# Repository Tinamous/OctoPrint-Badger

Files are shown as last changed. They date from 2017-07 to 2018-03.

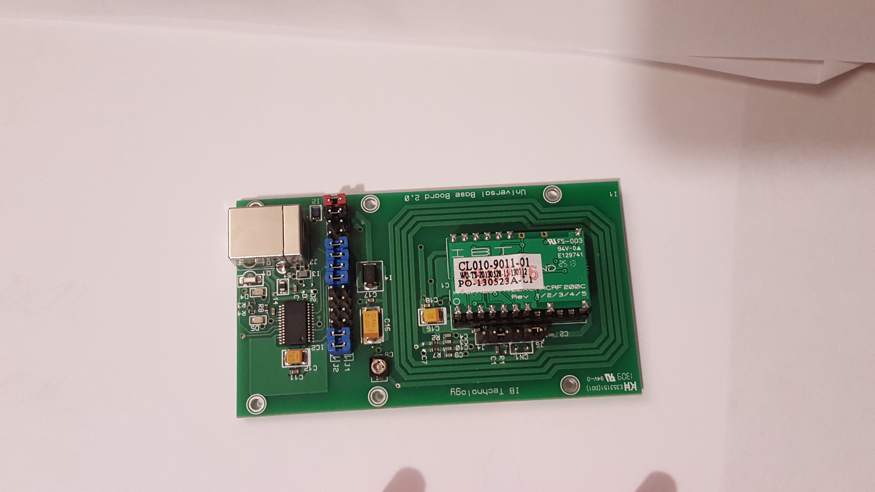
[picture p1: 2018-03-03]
Images/2017-08-05 03.23.46.jpg

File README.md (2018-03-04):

# OctoPrint-Badger

Prints 2D Badges/Labels.

Uses OctoPrint system to allow for "Do No Hack" labels to be printed on a Dymo Label Writer (for MakeSpace) using RFID tags.

Not really used for 3D printing unless you wish to modify and automate to print labels for when a print is finished or something.

## Setup

Hardware setup:

* Raspberry Pi 3
* Dymo LabelWriter 450
* IB Technology Micro RWD RFID reader (for Makespace door kep)
* 2x 28mm Arcade buttons with LEDs (Optional)
* Pi Power Hat (https://github.com/Tinamous/PiPowerHat) (optional) or 5V DC supply for Raspberry Pi
* Labels, lots of...

### Buttons:

Left Button:

* Switch Pin 1: GND
* Switch Pin 2: GPIO 26
* LED Pin 1: GND
* LED Pin 2: via 82R resistor to GPIO 16

Right Button: 

* Switch Pin 1: GND
* Switch Pin 2: GPIO 21
* LED Pin 1: GND
* LED Pin 2: via 82R resistor to GPIO 20

LED Indicator:

* GPIO 11 with 1k resistor going to GND (this is build on-board the Pi Power Hat)

### Software Installation

* Download and install OctoPi (https://octoprint.org/download/)
* Follow the Getting Started Guide for OctoPi.
* Install Cups
* Download and install the Dymo 450

#### Install CUPS:

sudo apt-get install libcups2-dev libcupsimage2-dev g++ cups cups-client

#### Install Dymo 450 Printer

The driver can be downloaded from:

http://www.dymo.com/en-US/dymo-label-sdk-and-cups-drivers-for-linux-dymo-label-sdk-cups-linux-p--1#

For convenience it's also in this repository:

* wget https://github.com/Tinamous/OctoPrint-Badger/raw/master/Notes/dymo-cups-drivers-1.4.0.tar.gz

* tar xvf dymo-cups-drivers-1.4.0.tar.gz
* cd dymo-cups-drivers-1.4.0.5/
* sudo ./configure
* sudo make
* sudo make install

Then add the Pi user to the printing group and enable remote admin

* sudo usermod -a -G lpadmin pi
* cupsctl --remote-admin

You should now be able to open a browser to the CUPS server:

* https://octopi.local:631/
* Add the printer (Administration/Add Printer/Select the 450).
* Select the label size (99012), quality (300x600) and select Barcode and Graphics as the default

#### Install OctoPrint-Badger plugin

Install via the bundled [Plugin Manager](https://github.com/foosel/OctoPrint/wiki/Plugin:-Plugin-Manager)
or manually using this URL:

    https://github.com/Tinamous/OctoPrint-Badger/archive/master.zip

The registration plug-in will most likely be needed as well, grab that from https://github.com/Tinamous/OctoPrint-Registration

Once installed configure the pluging settings to use the appropriate printer and RFID reader.

#### Remove Unwanted OctoPrint bits.

* cd ~/.octoprint/
* sudo nano config.yaml

Add/Update the following:

appearance:
  components:
    disabled:
      tab:
      - temperature
      - gcodeviewer
      - terminal
      - control
      - plugin_pipower
      - timelapse
      sidebar:
      - connection
      - state
      - files
    order:
      tab:
      - plugin_whosprinting

## Configuration

This is work in progress. Requires CUPS support to be installed. Please see the Notes folder for the time being.

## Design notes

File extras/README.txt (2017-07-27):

Currently Cookiecutter generates the following helpful extras to this folder:

Badger.md
    Data file for plugins.octoprint.org. Fill in the missing TODOs once your
    plugin is ready for release and file a PR as described at
    http://plugins.octoprint.org/help/registering/ to get it published.

This folder may be safely removed if you don't need it.

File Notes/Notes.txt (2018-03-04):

apt-get update
apt-get upgrade 

From: https://community.ubnt.com/t5/UniFi-Wireless/RPI-Dashbutton-Turn-RaspberryPI-with-Dymo-LabelWriter-into-a/td-p/1667513

sudo apt-get install libcups2-dev libcupsimage2-dev g++ cups cups-client

- Linux drivers: Download from: http://www.dymo.com/en-US/dymo-label-sdk-and-cups-drivers-for-linux-dymo-label-sdk-cups-linux-p--1#

Or get it from the project repository...
wget https://github.com/Tinamous/OctoPrint-Badger/raw/master/Notes/dymo-cups-drivers-1.4.0.tar.gz

tar xvf dymo-cups-drivers-1.4.0.tar.gz
cd dymo-cups-drivers-1.4.0/
sudo ./configure
sudo make
sudo make install

# Add Pi user to printers group

sudo usermod -a -G lpadmin pi

---
Add printer using cups...

Enable cups to be accessed off the pi
cupsctl --remote-admin

Browse to cups..
https://octopi.local:631/

Connect Dymo printer.

Add Dymo, set Media size to 11356 (White Name Badge - need to change this to something smaller)
Print Quality: Barcodes and Graphics)

NB:99012 actual label (Large Address 36mm x 89mm)

connection: usb://DYMO/LabelWriter%20450?serial=01010112345600

Not appropriate, but...
git clone https://github.com/Makespace/Badger

# Python imple - before adding plugin.

# Needed for python
sudo apt-get install python-cups

# See https://pypi.python.org/pypi/pycups

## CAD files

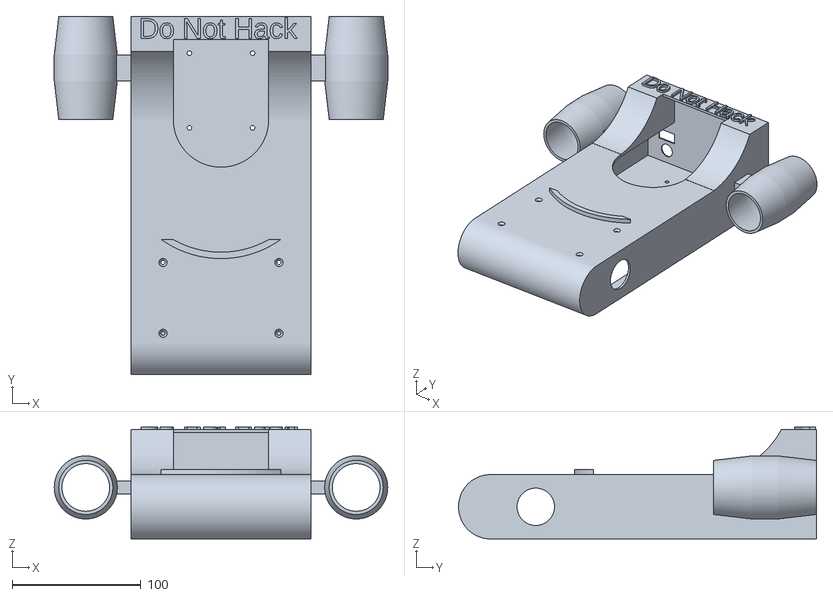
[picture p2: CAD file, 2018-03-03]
Case/OctoBadgerCase-full-WithEngines.stl
259.0 x 278.0 x 86.9

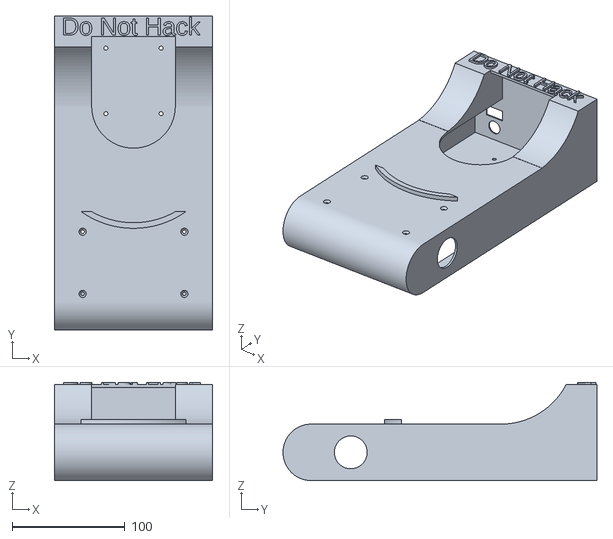
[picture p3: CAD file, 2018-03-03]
Case/OctoBadgerCase-full.stl
140.0 x 278.0 x 86.9

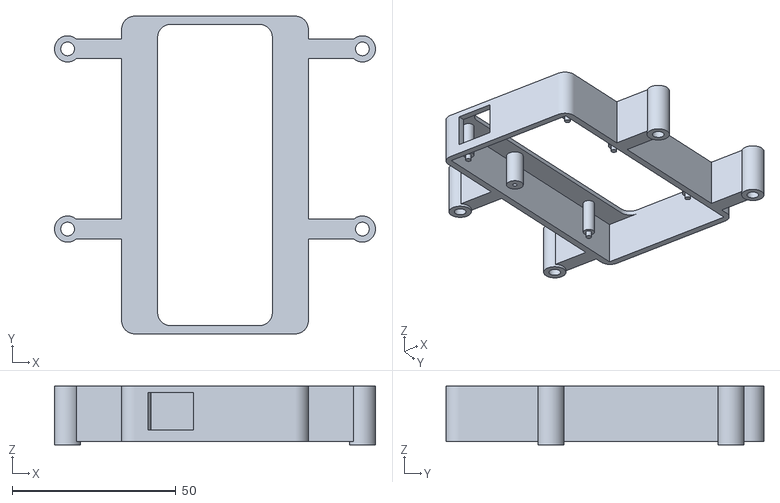
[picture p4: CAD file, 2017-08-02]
Case/RFID Sensor Mounts/CaseForRfidUniversalPcb.stl
98.0 x 97.0 x 18.0

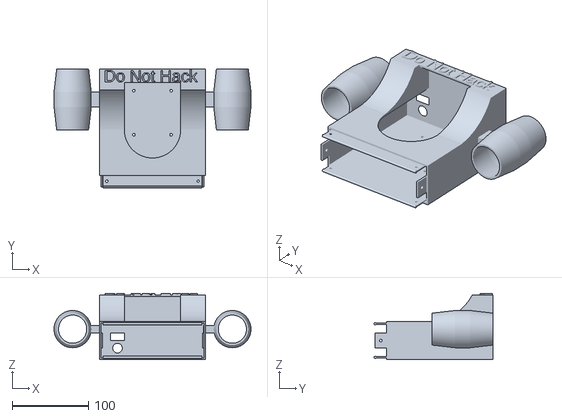
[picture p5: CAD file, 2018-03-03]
Case/OctoBadgerCase-Rear-WithEngines.stl
259.0 x 156.5 x 86.9

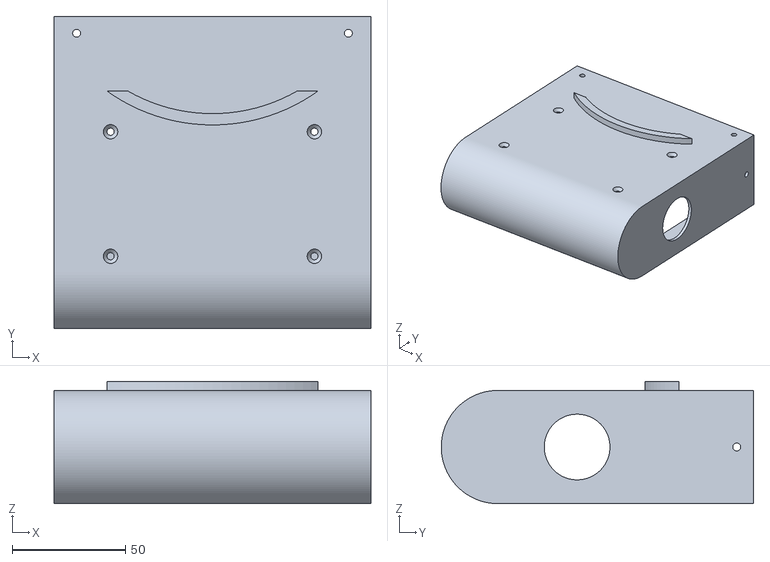
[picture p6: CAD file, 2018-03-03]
Case/OctoBadgerCase-front.stl
140.0 x 138.0 x 54.0

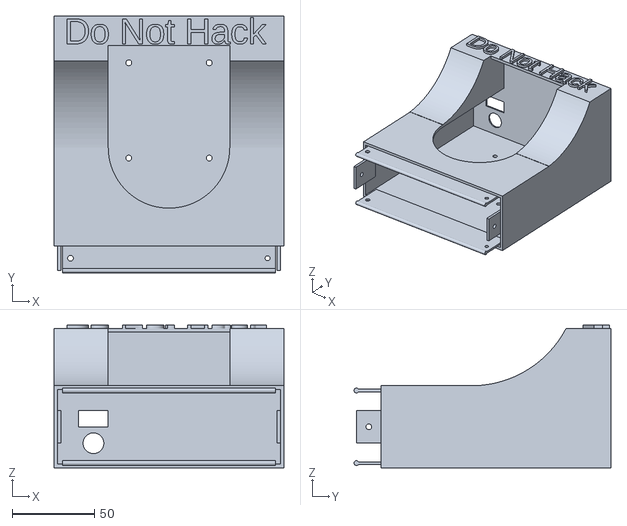
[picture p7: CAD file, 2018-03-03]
Case/OctoBadgerCase-Rear.stl
140.0 x 156.5 x 86.9

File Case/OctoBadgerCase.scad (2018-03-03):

caseWidth = 140; // Was 110 but label writer sticks out 10mm on each side 
caseHeight = 50; //45
$fn=120;

//rfidCaseLength = 125;
rfidCaseLength = 113;
wallWidth = 2;
// Allow for the join esction lip.
piCaseWallWidth = wallWidth + 0.2;

//printAllAtOnce = true;
printRfidSection = true;
printPiSection = true;
printPiEngines = true;
// If printing both at the same time then
// don't bother with the joing section and holes.
printAllAtOnce = printRfidSection && printPiSection;

includeSideButtons = true;
switchCutoutDiameter = 29;

includeUsbHole = false;

module showModels() {
    // Our case is 110mm wide
    // dymo is 125 so hase 15mm overhand (7.5mm each side)
    // back Pi case to start 70mm in (at our y=0)
    // front RFID case to be about 50mm in front of the printer
    translate([(caseWidth - 125)/2,-65,caseHeight + 00]) {
        //%labelWriter();
    }

    if (printPiSection) {
        // Place the Pi dead centeral.
        translate([(caseWidth - 56)/2, 35, 5]) {
            %raspberryPi();
        }
    }

    if (printRfidSection) {        
        translate([(caseWidth - 57)/2, -rfidCaseLength -3, caseHeight-20]) {    
          //  %rfidModule();
        }
    }
}

// Show a model of the Raspberry Pi to check sizing
module raspberryPi() {
    
    // Rasberry Pi main body
    cube([56, 80, 30]); // 65mm + USB/Ethernet port.
    
    // USB Connections
    translate([56-35,-53,5]) {
        cube([35, 53, 30]);
    }
    
    translate([5,80,30]) {
        cube([12, 20, 20]);
    }
    
    // With connectors and supports.
    cube([56, 80, 45]);
    
    // 4 Pin power connector (connect printer power when running 24V into Pi Power Hat)
    translate([3,80-25,30]) {
        cube([12, 4, 20]);
    }
    
    // Holes.
    translate([0,80-65,-10]) {
        piScrewHoles(2.8);
    }
}

module piScrewHoles(d) {
h = 40;
    translate([3.5,3.5,0]) {
        cylinder(d=d,h=h);
    }
    translate([52.5,3.5,0]) {
        cylinder(d=d,h=h);
    }
    translate([52.5,61.5,0]) {
        cylinder(d=d,h=h);
    }
    translate([3.5,61.5,0]) {
        cylinder(d=d,h=h);
    }
}

// Show a model of the RFID module to check sizing
module rfidModule() {
    cube([57, 97, 18]);
    
    // Hidhlight the rfid area
    // aerial 57mm diameter, 3mm offset from case edge + 5mm from pcb
    translate([57/2,57/2+5,10]) {
        cylinder(d=50, h=20);
    }

    
    // USB Plug
    translate([5,90,6]) {
        #cube([12, 50, 12]);
    }
    
    // Centered.
    //translate([(caseWidth - 50)/2 + 50, -140+10, caseHeight-5]) {    
        
    // Holes 90mm appart
    // rfid case is 57mm.
    translate([-(90-57)/2, 10, 0]) {    
        rfidScrewHoles(3.2);
    }
}

// Holes in rfid case 90 x 60mm appart.
module rfidScrewHoles(d) {
    
h=60;
    translate([0,0,0]) {
        cylinder(d=d,h=h);
    }
    translate([90,0,0]) {
        cylinder(d=d,h=h);
    }
    translate([0,55,0]) {
        cylinder(d=d,h=h);
    }
    translate([90,55,0]) {
        cylinder(d=d,h=h);
    }
}

module rfidScrewHolesCountersunk(d) {
    
h=wallWidth+0.2;
d2 = 6.5; // M3 countsunk head size
    translate([0,0,0]) {
        cylinder(d1=d,d2=d2, h=h);
    }
    translate([90,0,0]) {
        cylinder(d1=d,d2=d2,h=h);
    }
    translate([0,55,0]) {
        cylinder(d1=d,d2=d2,h=h);
    }
    translate([90,55,0]) {
        cylinder(d1=d,d2=d2,h=h);
    }
}
    

module labelWriter() {
    difference() {
        union() {
            cube([125, 185, 140]);
        }
        union(){ 
            translate([(125 - 55)/2, 125 ,-0.1]) {
                cube([55, 45, 20]);
            }
            translate([(125 - 40)/2, 125 ,-0.1]) {
                cube([40, 65, 20]);
            }
        }
    }
}

baseCutout = 100;
baseCutoutOffset = (caseWidth - baseCutout)/2;

// Rear half of the case containing the Raspberry
// Pi.
module piCase() {
    
    
    // Front Section of the back half
    difference() {
        union() {
            cube([caseWidth, 60, caseHeight]);
        }
        union() {
            // Hollow the part below the printer
            translate([piCaseWallWidth,-1,piCaseWallWidth]) {
                cube([caseWidth-(piCaseWallWidth*2), 62, caseHeight-(piCaseWallWidth*2)]);
            }
                        
            // Put a curve in the top to help 
            translate([caseWidth/2,60,caseHeight-5]) {
                rotate([0,0,90]) {
                    cylinder(d=74, h=10);
                }
            }
            
            // This section overlaps with the back so ensure we have 
            // the screwholes set here as well.
            translate([(caseWidth - 56)/2,60 - 10,-5]) {
                #piScrewHoles(3.6);
            }
        }
    }
    
    
    // Back section of the back half
    translate([0,60,0]) {
        difference() {
            union() {
                cube([caseWidth, 80, 35 + caseHeight]);
            }
            union() {               
                // Hollow the part below the printer
                translate([piCaseWallWidth,-0.1,piCaseWallWidth]) {
                    cube([caseWidth-(piCaseWallWidth*2), 80-0.9, caseHeight-(piCaseWallWidth*2)]);
                }
                
                // Curve the end for the printer to sit into
                translate([-0.1,-5,caseHeight + 65]) {
                    rotate([0,90,0]) {
                        cylinder(d=130, h=caseWidth+0.2);
                    }
                }
                
                // Cut out the square recess for printer cable
                translate([(caseWidth-74)/2,-1,caseHeight-(piCaseWallWidth+1)]) {
                    cube([74, 80, 38 - piCaseWallWidth]);
                }
                
                // Repeat cutout but to include part of the top section as well.
                translate([(caseWidth-74)/2,-1,caseHeight-2]) {
                    cube([74, 54 + 9, 40]);
                }
                
                // Hole for the power connector.
                powerHoleDiameter = 12.6;
                //translate([caseWidth/2,82,70]) {
                translate([15+9,82,10 + 5]) {
                    rotate([90,0,0]) {
                        cylinder(d=powerHoleDiameter, h=5);
                    }
                }
                
                // Hole for USB lead for Pi.
                if (includeUsbHole) {
                    translate([15,75,25]) {
                            #cube([18, 10, 10]);
                    }
                }
                
                // Holes for Raspberry Pi.
                translate([(caseWidth - 56)/2,-10,-5]) {
                    piScrewHoles(3.6);
                }
            }
        }
    }
    
    if (!printAllAtOnce) {
        // Add joint senction to help join to the rfid section
        difference() {
            union() {           
                // Use RFID wall width (smaller than this)
                // to align the joint section with the rfid case
                
                translate([wallWidth+0.1,-15,wallWidth+0.1]) {
                    // wallWidth is wall width
                    // so 0.1mm smaller all around
                    //cube([caseWidth - 3.6, 25, caseHeight - 3.6]);
                }
                
                translate([5,-15, wallWidth+0.1]) {
                    #cube([caseWidth-10, 25,1.6]);
                    translate([0,0,1.6/2]) {
                        rotate([0,90,0]) {
                            cylinder(d=3, h=caseWidth-10);
                        }
                    }
                }
                
                // 2mm thick so drop down 2.1mm for thickness
                // + fitting tollerance.
                translate([5,-15,caseHeight - (wallWidth+1.7)]) {
                    #cube([caseWidth-10, 25,1.6]);
                    translate([0,0,1.6/2]) {
                        rotate([0,90,0]) {
                            cylinder(d=3, h=caseWidth-10);
                        }
                    }
                }
                
                // Side parts for bolts.
                translate([wallWidth+0.1,-15,(caseHeight/2)-10]) {
                    cube([2, 25,20]);
                }
                
                translate([caseWidth - (wallWidth+0.1+2),-15,(caseHeight/2)-10]) {
                    cube([2, 25,20]);
                }
                
                // TODO: Add M4 Cylinder to top/bottom for latching.
            }
            union() {
                translate([0,-15.001,0]) {                
                    translate([baseCutoutOffset,-0.1,0]) {
                        //#cube([caseWidth - (2 * baseCutoutOffset), 40.2, 4]);
                    }
                    
                    // Add holes to allow the sections to be bolted together
                    // Left
                    translate([10,7.5,-2]) {
                        cylinder(d=3.5, h=caseHeight+10);
                    }
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

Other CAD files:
Case/OctoBadgerCase-Full-WithEngines-NoButtons.stl

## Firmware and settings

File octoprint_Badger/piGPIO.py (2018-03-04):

# coding=utf-8
from __future__ import absolute_import

__author__ = "Stephen Harrison <Stephen.Harrison@AnalysisUK.com>"
__license__ = 'Creative Commons Share Alike 4.0'
__copyright__ = "Copyright (C) 2018 Analysis UK Ltd - Released under terms of the CC-SA-4.0 License"

from octoprint.util import RepeatedTimer

# Interface for real hardware on the raspberry Pi
class PiGPIO:
	def __init__(self, logger, settings, event_bus):
		self._logger = logger
		self._settings = settings
		self._event_bus = event_bus
		self._left_button_pin = 26
		self._left_led_pin = 16
		self._right_button_pin = 21
		self._right_led_pin = 20
		self._im_alive_pin = 11

		self._left_led_mode = 0
		self._right_led_mode = 0

		self._both_puttons_pressed = False
		self._leds_flash_on = True
		self._timer = RepeatedTimer(0.25, self.timer_tick)

	def initialize(self):
		self._logger.info("Init RasPi GPIO...")

		# This will probably need to be extracted as it will
		# fail on PC when running in debug mode.
		import RPi.GPIO as GPIO

		# Left and right buttons
		GPIO.setup(self._left_button_pin, GPIO.IN, pull_up_down=GPIO.PUD_UP)
		GPIO.setup(self._right_button_pin, GPIO.IN, pull_up_down=GPIO.PUD_UP)

		# Alive LED on Pi Power Hat.
		GPIO.setup(self._im_alive_pin, GPIO.OUT)

		# Left and right button LEDs
		GPIO.setup(self._left_led_pin, GPIO.OUT)
		GPIO.setup(self._right_led_pin, GPIO.OUT)

		# And turn on all the LEDs :-)
		self.set_alive_led(1)
		self.set_left_button_led(1)
		self.set_right_button_led(1)
		self._timer.start()

	def set_alive_led(self, state):
		self._logger.info("Setting Alive LED")
		import RPi.GPIO as GPIO
		GPIO.output(self._im_alive_pin, state)

	def is_left_button_pressed(self):
		import RPi.GPIO as GPIO
		# Buttons are on pull-ups
		return not GPIO.input(self._left_button_pin)

	# State: 0 - off, 1 - on, 2 - blink
	def set_left_button_led(self, state):
		self._logger.info("Setting left button LED state: {0}".format(state))
		self._left_led_mode = state
		self.set_led_state(self._left_led_pin, state)

	def is_right_button_pressed(self):
		import RPi.GPIO as GPIO
		# Buttons are on pull-ups
		return not GPIO.input(self._right_button_pin)

	# State: 0 - off, 1 - on, 2 - blink
	def set_right_button_led(self, state):
		self._logger.info("Setting right button LED state: {0}".format(state))
		self._right_led_mode = state
		self.set_led_state(self._right_led_pin, state)

	def set_led_state(self, pin, state):
		import RPi.GPIO as GPIO
		if state == 0:
			GPIO.output(pin, False)
		else:
			GPIO.output(pin, True)

	def timer_tick(self):
		self._leds_flash_on = not self._leds_flash_on
		state = 0
		if self._leds_flash_on:
			state = 1

		if self._left_led_mode == 2:
			self._logger.info("Flashing Left LEDs....")
			self.set_led_state(self._left_led_pin, state)

		if self._right_led_mode == 2:
			self._logger.info("Flashing right LEDs....")
			self.set_led_state(self._right_led_pin, state)

		# Whilst we are on a timer tick..
		if self.is_left_button_pressed() & self.is_right_button_pressed():
			# Only fire the event once allowing for the buttons to
			# be released.
			if not self._both_puttons_pressed:
				self._both_puttons_pressed = True
				payload = dict()
				self._event_bus.fire("BothButtonsPressed", payload)
		else:
			self._both_puttons_pressed = False

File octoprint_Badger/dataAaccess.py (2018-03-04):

import sqlite3
import datetime

class DataAccess:
	def __init__(self, logger, settings, data_folder):
		self._logger = logger
		self._settings = settings
		self._data_folder = data_folder
		self._dbname = data_folder + "/badger.db"

		self._logger.info("Initialize Data Access")

		# Setup the database
		try:
			conn = sqlite3.connect(self._dbname)
			db = conn.cursor()

			self._logger.info("+++++++++++++++++++++++++++++++++++++++++++++++++++++++++++++++++++++++++")
			self._logger.info("Create label counter")

			# Single entry database table used on startup to load the number of labels
			# printed on the current roll.
			db.execute('CREATE TABLE IF NOT EXISTS label_counter(id INTEGER PRIMARY KEY, labels_printed Number, labels_remaining Number, roll_number Number, replaced_at DateTime )')

			self._logger.info("Create serial number")

			# Single entry table to store the last number of the label.
			# uses ROWNUMBER from create label?!?!?
			db.execute('CREATE TABLE IF NOT EXISTS serial_number(id INTEGER PRIMARY KEY, serial INTEGER )')

			self._logger.info("Create item")

			# details of an item left
			# "Do Not Hack" or "Hack Me" item.
			db.execute('CREATE TABLE IF NOT EXISTS item(full_serial Text PRIMARY KEY, date_left DateTime, remove_after DateTime, user_name Text, comment Text, removed INTEGER, date_removed DateTime)')
		except Exception as e:
			self._logger.error("Failed to setup database. Error: {0}".format(e))


	def update_labels_used(self):
		sql = "SELECT id, labels_printed, labels_remaining FROM label_counter"
		rows = self.query(sql)

		if rows:
			# TODO: Ensure only a single row.
			row = rows[0]
			id = row[0]
			labels_printed = int(row[1])
			labels_remaining = int(row[2])

			labels_printed +=1
			labels_remaining -=1

			sql = "UPDATE label_counter SET labels_printed = " + str(labels_printed) + ", labels_remaining = " + str(labels_remaining) + "  WHERE id = " + str(id)
		else:
			sql = "INSERT INTO label_counter (labels_printed, labels_remaining, roll_number) VALUES ('%s', '%s', '%s')" % (1, 259, 1)

		self.execute(sql)


	def update_new_roll(self):
		sql = "SELECT id, roll_number FROM label_counter"

		if rows:
			# TODO: Ensure only a single row.
			row = rows[0]
			id = row[0]
			roll_number = int(row[1])
			roll_number +=1

			sql = "UPDATE label_counter SET roll_number = " + str(roll_number) + ", labels_remaining = " + str(260) + ",replaced_at = " + datetime.datetime.today() + "  WHERE id = " + str(id)
		else:
			sql = "INSERT INTO label_counter (labels_printed, labels_remaining, roll_number, replaced_at) VALUES ('%s','%s', '%s', '%s', '%s')" % (0, 260, 1, 250, datetime.datetime.today())

		self.execute(sql)


	def get_serial_number(self):
		serial = 13

		sql = "SELECT id,serial FROM serial_number"
		rows = self.query(sql)

		if rows:
			# TODO: Ensure only a single row.
			row = rows[0]
			id = row[0]
			serial = int(row[1])
			serial = serial + 1
			sql = "UPDATE serial_number SET serial = " + str(serial) + " WHERE id = " + str(id)

		else:
			sql = "INSERT INTO serial_number (serial) VALUES ('%s')" % (serial)


		self.execute(sql)
		return serial

	def store_item(self, serial,  user_name, remove_after):
		sql = "INSERT INTO item (full_serial, date_left, remove_after, user_name, comment, removed) VALUES ('%s', '%s', '%s', '%s', '', '0')" % (serial, datetime.datetime.today(), remove_after, user_name)
		self.execute(sql)

	def execute(self, sql):
		conn = sqlite3.connect(self._dbname)
		db = conn.cursor()

		db.execute(sql)
		conn.commit()
		conn.close()

	def query(self, sql):
		conn = sqlite3.connect(self._dbname)
		db = conn.cursor()

		db.execute(sql)
		try:
			return db.fetchall()
		finally:
			conn.close();

#  sql = "INSERT INTO connected (event_time, port, baudrate) VALUES ('%s', '%s', '%s')" % (datetime.datetime.today(), port, baudrate)

# sql = "SELECT hour, connected, disconnected, upload, print_started, print_done, print_failed, print_cancelled, print_paused, print_resumed, error FROM hourstat"
# rows = self.statDB.query(sql)
# hour.append(row[0])

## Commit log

2017-07-29 Fleshed out more implementation.
    Improved notes on how to install additional drivers etc. required.
    Removed user registration/update as this is now a seperate plugin (OctoPrint-Registration)
2017-07-29 Added OctoPrint data folder for printers
2017-07-29 Fixed connection self.conn -> self._conn
    [cupsLabelPrinter.py]
2017-07-29 Update for using the configured printer.
2017-07-29 Added firing of print events to other plugins can be used and capture labels being printed.
    Implemented Micro RWD RFID reader.
    Minor modification for label printing.
2017-07-30 Split out labels to their own class files.
    Updated classes to be Pascal case.
    Added setting for the remove after period.
2017-07-30 Added serial number to the RHS of the member name for tracking.
    Set to 36mm height as that's the height for 99012 labels (I'd been using 11356).
    shifted things up a little.
2017-07-30 Fix for missing contact details and hopeful fix for Raspberry Pi's IP Address.
    [largeAddressLabel.py]
2017-07-30 Add print label for members boxes.
    Moved common label functions into SuperLabel label base class.
    Added work in progress configuration options.
    Added start of print queue management.
2017-07-30 Start of case of Pi and RFID sensor to sit underneath the label writer.
    [OctoBadgerCase.scad, OctoBadgerCase.stl]
2017-08-01 Update to list the actual printers on the system.
    UI improvements.
2017-08-01 Added joint holes and improved front section.
    [OctoBadgerCase-Rear.stl, OctoBadgerCase-front.stl, OctoBadgerCase-full.stl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]
2017-08-01 Trying to get cups printers before being initialized.
2017-08-01 Removed ctor and logging from cups printer and get printers.
2017-08-01 Added printer info details to the UI and label type details to the notificaitons.
2017-08-01 Made joint section sticking out slightly smaller than the inside to aid easier fitting .
    [OctoBadgerCase-Rear.stl, OctoBadgerCase.scad]
2017-08-02 Set labelwriter back a bit. added complete module for rfid with case.
    [CaseForRfidUniversalPcb.stl, OctoBadgerCase-front.stl, OctoBadgerCase.scad]
2017-08-02 Made wider and thicker.
    Rear half only so far:
    Removed middle joint hole and added holes to sides for connection, added cylinders to aid connection of two halves.
    Added hole for USB connector, moved Pi to one side and better located the power inlet for the printer.
    [OctoBadgerCase-Rear.stl, OctoBadgerCase.scad]
2017-08-03 Correctedess for front case.
    Made front curve to catch labelwriter higher and forward 2mm.
    Added options for automated building for back/front or to build all at once without body joints.
    Added countersink for RFID screws
    [OctoBadgerCase-Rear.stl, OctoBadgerCase-front.stl, OctoBadgerCase-full.stl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]
2017-08-03 Fixed overlap of
    [OctoBadgerCase-front.stl, OctoBadgerCase-full-WithEngines.stl, OctoBadgerCase.scad]
2017-08-04 Full fresh build of all the stl's. Moved the case for the universal RFID sensor to RFID sensor mounts folder.
    [CaseForRfidUniversalPcb.stl, OctoBadgerCase-Rear-WithEngines.stl, OctoBadgerCase-Rear.stl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]
2017-08-31 Formatting and ; fix up for Javascript, changed event handler to switch statement and remomoved auto getPrintQueue on event in case this is causing the crashes.
2017-08-31 Reduced logging noise a little for tag reading.
    [microRWDHiTag2Reader.py]
2017-08-31 Minor update to improve logging and fix path to use "/" otherwise the files do not go into the correct folder on the Pi.
    [SuperLabel.py, cupsLabelPrinter.py, largeAddressLabel.py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]
2017-08-31 Moved buttons for print queue into the print queue section.
2018-03-03 Made the case slightly higher to allow for connectors on the Pi.
    Added side holes for 28mm buttons.
    Made USB hole optional.
    [OctoBadgerCase-Full-WithEngines-NoButtons.stl, OctoBadgerCase-Rear-WithEngines.stl, OctoBadgerCase-Rear.stl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]
2018-03-04 Work in progress...
    Added button handling for different label types.
    Minor improvements to label counting.
    Start of HACK Me and badger namebadge labels.
2018-03-04 Buttons are pull-up, so will be low when pressed.
    Inproved both button detect so it only fites once when held
2018-03-04 Added database for item tracking.
    Changed tag release to require 6 no-tag readings before accepting the tag has been remove to try and prevent random no tag issues.
    Improved labels
    [SuperLabel.py, cupsLabelPrinter.py, dataAaccess.py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]
2018-03-04 Turning LEDs off whilst printing to get an idea of how long it takes.
    And a few Minor house keeping updates.
